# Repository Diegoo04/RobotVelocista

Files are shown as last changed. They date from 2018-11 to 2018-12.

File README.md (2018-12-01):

# RobotVelocista
Robot velocista /// Race robot ///
Placa frontal:
-Primer día:
  Hoy hemos hecho el esquema de la placa de los sensores y hemos empezado a hacer la PCB.🏎🔥
-Segundo día:
  Hoy he enrutado las redes y ahora estoy nombrando los pines en la placa.✏
-Tercer día:
  Hoy he terminado de nombrar los pines de la pcb.
Placa principal:
-Tercer día:
  Hoy hemos empezado el esquema de los modulos de la placa(Microconector,Conectores auxiliares) y he hecho los flags.

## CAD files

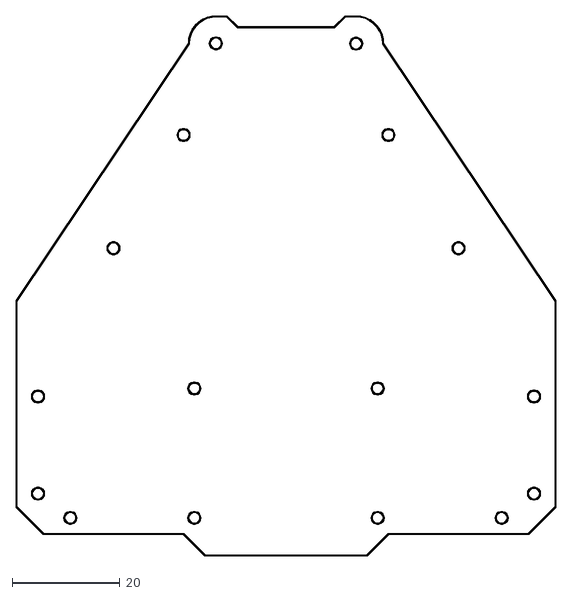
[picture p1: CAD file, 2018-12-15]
core/Main_board-Edge.Cuts.dxf
100.2 x 100.2

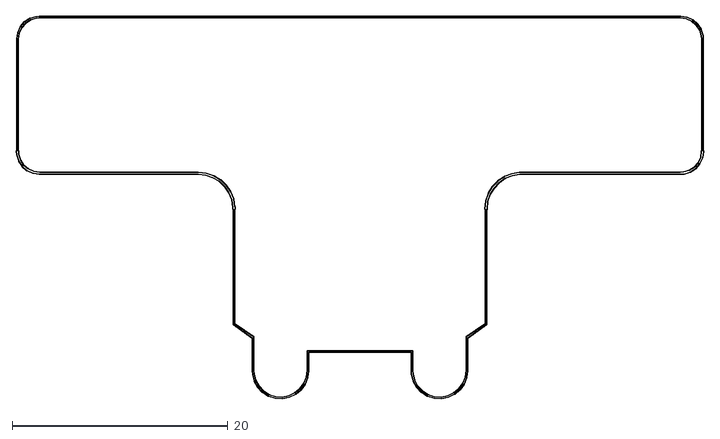
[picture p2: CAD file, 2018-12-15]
core/sensores-Edge.Cuts.dxf
63.7 x 35.5

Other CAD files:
core/Main_board-F.SilkS.dxf

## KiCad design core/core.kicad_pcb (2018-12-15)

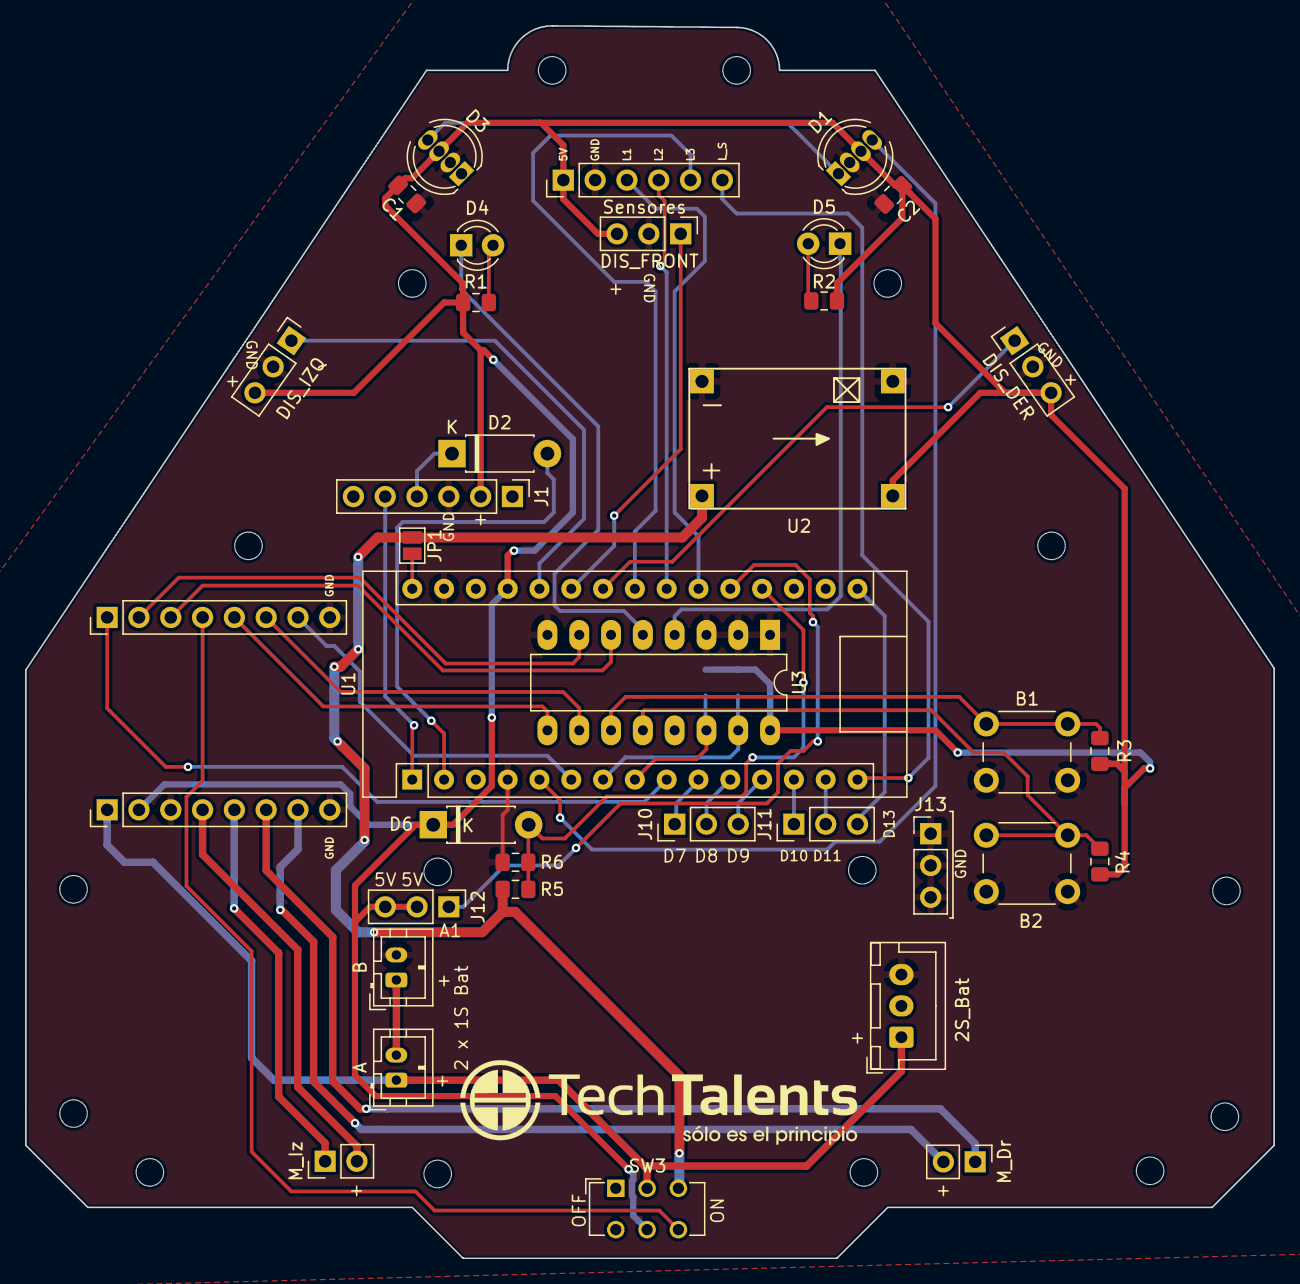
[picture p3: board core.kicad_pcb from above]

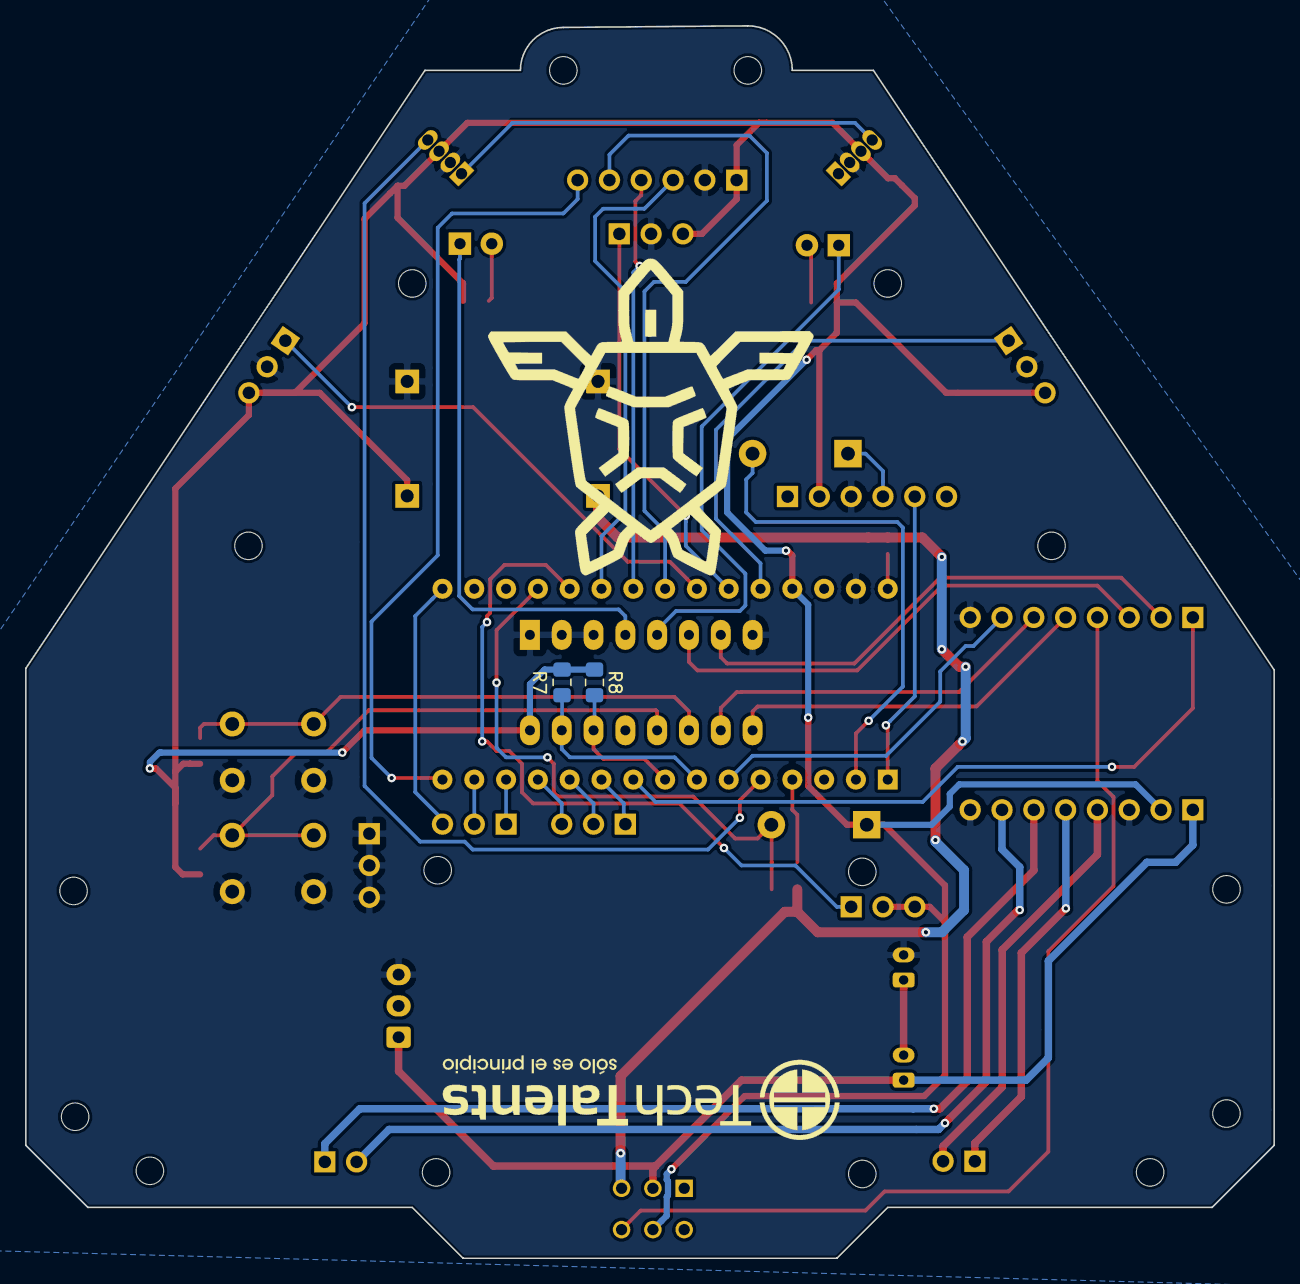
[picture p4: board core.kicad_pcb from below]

Board: 2 copper layers, 99.7 x 98.4 mm, 39 parts (2 on the bottom side), 45 nets.

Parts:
2S_Bat: LIPO_2S; JST_XH_B03B-XH-A_1x03_P2.50mm_Vertical
A: LIPO_1S_A; JST_PH_B2B-PH-K_1x02_P2.00mm_Vertical
B: LIPO_1S_B; JST_PH_B2B-PH-K_1x02_P2.00mm_Vertical
B1: B1; SW_PUSH_6mm
B2: B2; SW_PUSH_6mm
C1, C2: 100nF; C_0805_2012Metric_Pad1.15x1.40mm_HandSolder
D1: NEO1; LED_D5.0mm-4_RGB
D2: 1N4148; D_DO-41_SOD81_P7.62mm_Horizontal
D3: NEO2; LED_D5.0mm-4_RGB
D4: ROJO; LED_D3.0mm
D5: VERDE; LED_D3.0mm
D6: 1N4001; D_DO-41_SOD81_P7.62mm_Horizontal
DIS_DER: DIST_DCHA; PinHeader_1x03_P2.54mm_Vertical
DIS_FRONT: DIST_FRONT; PinHeader_1x03_P2.54mm_Vertical
DIS_IZQ: DIST_IZQ; PinHeader_1x03_P2.54mm_Vertical
J1: HC-05; PinHeader_1x06_P2.54mm_Vertical
J2: TB6612FNG_A; PinHeader_1x08_P2.54mm_Vertical
J5: TB6612FNG_B; PinHeader_1x08_P2.54mm_Vertical
J10: AUX1; PinHeader_1x03_P2.54mm_Vertical
J11: AUX2; PinHeader_1x03_P2.54mm_Vertical
J12: AUX3; PinHeader_1x03_P2.54mm_Vertical
J13: AUX4; PinHeader_1x03_P2.54mm_Vertical
JP1: Jumper; SolderJumper-2_P1.3mm_Open_Pad1.0x1.5mm
M_Dr: MOT_DER; PinHeader_1x02_P2.54mm_Vertical
M_Iz: MOT_IZQ; PinHeader_1x02_P2.54mm_Vertical
R1, R2: 220; R_0805_2012Metric_Pad1.15x1.40mm_HandSolder
R3, R4: 10K; R_0805_2012Metric_Pad1.15x1.40mm_HandSolder
R5: 82K; R_0805_2012Metric_Pad1.15x1.40mm_HandSolder
R6: 120K; R_0805_2012Metric_Pad1.15x1.40mm_HandSolder
R7, R8: 1k; R_0805_2012Metric_Pad1.15x1.40mm_HandSolder
SW3: SW_DPDT_x2; SW_CuK_JS202011CQN_DPDT_Straight
Sensores: Sensores_linea; PinHeader_1x06_P2.54mm_Vertical
U1: Arduino_Nano_v3.x; Arduino_Nano
U2: DC-DC_BuckModule; DC-DC-MP2307
U3: PCF8574; DIP-16_W7.62mm_LongPads

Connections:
+5V: C1.2, C2.2, D1.3, D3.3, D6.1, DIS_DER.3, DIS_FRONT.3, DIS_IZQ.3, J1.2, J2.2, J12.2, J12.3, R1.1, R2.1, R3.1, R4.1, R7.1, R8.1, SW3.5, Sensores.1, U1.27, U2.3, U3.16
A1: J12.1, U1.20
B1: B1.1, R3.2, U3.11
B2: B2.1, R4.2, U3.12
BAT: D6.2, R5.2, R6.1, U1.19
BT_RX: J1.5, U1.1
BT_TX: D2.2, U1.2
D7: J10.1, U1.10
D8: J10.2, U1.11
D9: J10.3, U1.12
D10: J11.1, U1.13
D11: J11.2, U1.14
D13: J11.3, U1.16
DIR_DER_1: J5.5, U3.9
DIR_DER_2: J5.6, U3.10
DIR_IZQ_1: J5.3, U3.6
DIR_IZQ_2: J5.2, U3.7
DIST_DCHA: DIS_DER.1, U1.24
DIST_FRONT: DIS_FRONT.1, U1.25
DIST_IZQ: DIS_IZQ.1, U1.26
GND: 2S_Bat.3, B.2, B1.2, B2.2, C1.1, C2.1, D1.2, D3.2, DIS_DER.2, DIS_FRONT.2, DIS_IZQ.2, J1.3, J2.3, J2.8, J5.8, J13.1, J13.2, J13.3, R6.2, Sensores.2, U1.4, U1.29, U2.2, U2.4, U3.1, U3.2, U3.3, U3.8
I2C_SCL: R8.2, U1.8, U3.14
I2C_SDA: R7.2, U1.7, U3.15
LED_G: D5.1, U3.4
LED_R: D4.1, U3.5
LINEA_1: Sensores.3, U1.21
LINEA_2: Sensores.4, U1.22
LINEA_3: Sensores.5, U1.23
LINEA_SEL: Sensores.6, U1.15
M_DER_+: J2.7, M_Dr.2
M_DER_-: J2.6, M_Dr.1
M_IZQ_+: J2.4, M_Iz.2
M_IZQ_-: J2.5, M_Iz.1
NEO: D1.4, U1.5
unnamed: D1.1, D3.4
unnamed: D2.1, J1.4
unnamed: D4.2, R1.2
unnamed: D5.2, R2.2
unnamed: A.2, B.1
PWM_DER: J5.7, U1.6
PWM_IZQ: J5.1, U1.9
STBY_MOT: J5.4, SW3.6
VBAT: 2S_Bat.1, A.1, J2.1, SW3.2
VCC: JP1.2, U1.30
VDD: JP1.1, R5.1, SW3.3, U2.1

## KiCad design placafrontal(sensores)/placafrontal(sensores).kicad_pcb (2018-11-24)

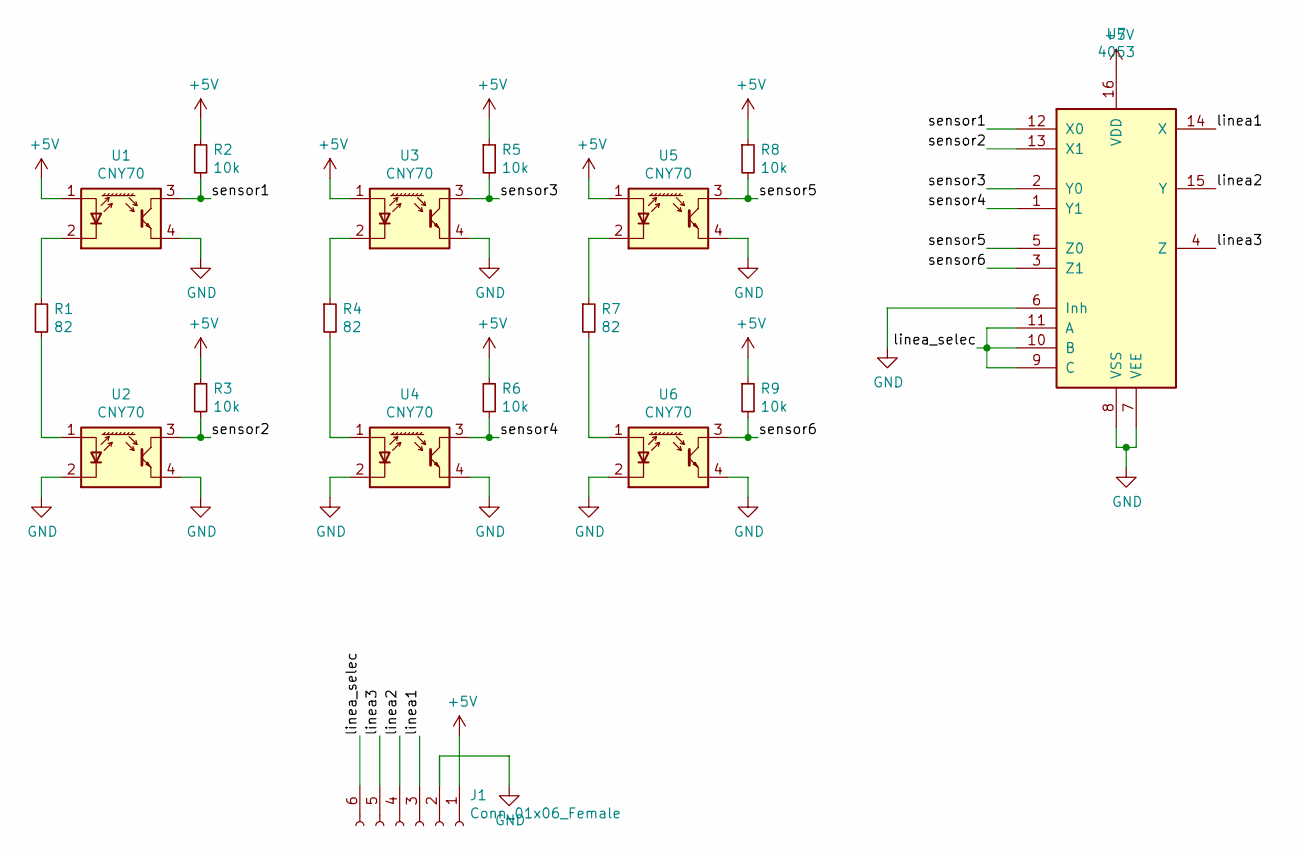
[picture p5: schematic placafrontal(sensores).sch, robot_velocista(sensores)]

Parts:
J1: Conn_01x06_Female; PinHeader_1x06_P1.27mm_Vertical
R1, R4, R7: 82; R_0805_2012Metric_Pad1.15x1.40mm_HandSolder
R2, R3, R5, R6, R8, R9: 10k; R_0805_2012Metric_Pad1.15x1.40mm_HandSolder
U1, U2, U3, U4, U5, U6: CNY70; Vishay_CNY70
U7: 4053; DIP-16_W7.62mm_LongPads

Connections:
+5V: J1.1, R2.1, R3.1, R5.1, R6.1, R8.1, R9.1, U1.1 (A), U3.1 (A), U5.1 (A), U7.16 (VDD)
/linea1: J1.3, U7.14 (X)
/linea2: J1.4, U7.15 (Y)
/linea3: J1.5, U7.4 (Z)
/linea_selec: J1.6, U7.9 (C), U7.10 (B), U7.11 (A)
/sensor1: R2.2, U1.3 (C), U7.12 (X0)
/sensor2: R3.2, U2.3 (C), U7.13 (X1)
/sensor3: R5.2, U3.3 (C), U7.2 (Y0)
/sensor4: R6.2, U4.3 (C), U7.1 (Y1)
/sensor5: R8.2, U5.3 (C), U7.5 (Z0)
/sensor6: R9.2, U6.3 (C), U7.3 (Z1)
GND: J1.2, U1.4 (E), U2.2 (K), U2.4 (E), U3.4 (E), U4.2 (K), U4.4 (E), U5.4 (E), U6.2 (K), U6.4 (E), U7.6 (Inh), U7.7 (VEE), U7.8 (VSS)
unnamed: R1.1, U1.2 (K)
unnamed: R1.2, U2.1 (A)
unnamed: R4.1, U3.2 (K)
unnamed: R4.2, U4.1 (A)
unnamed: R7.1, U5.2 (K)
unnamed: R7.2, U6.1 (A)

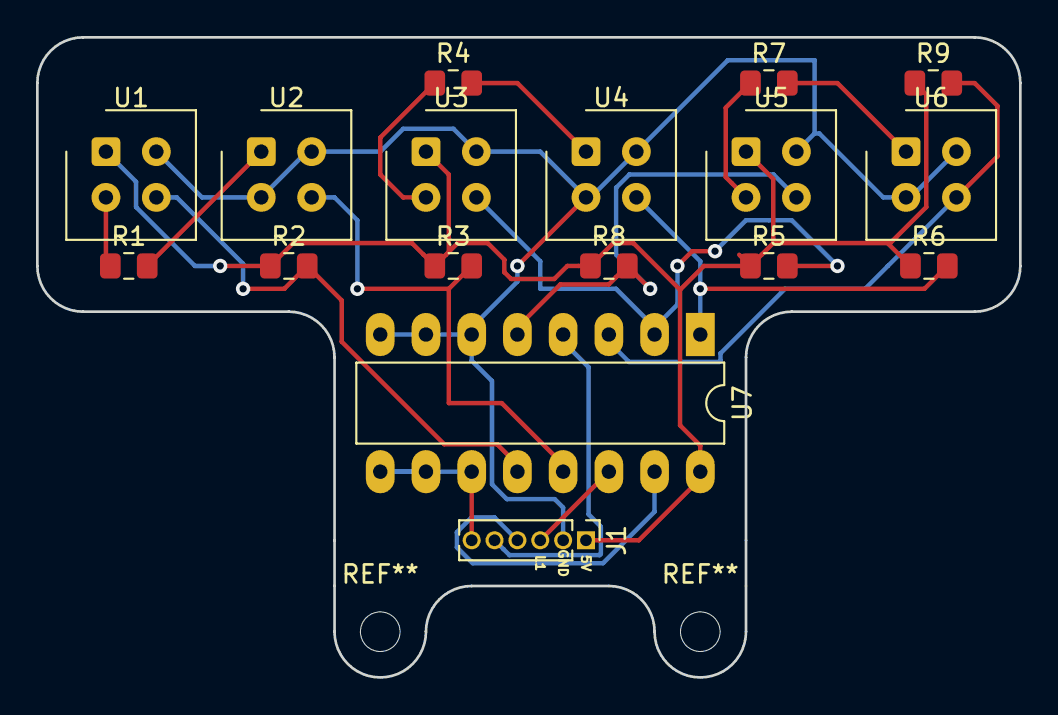
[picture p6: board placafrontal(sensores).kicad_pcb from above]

Board: 2 copper layers, 54.6 x 35.6 mm, 17 parts (0 on the bottom side), 18 nets.
